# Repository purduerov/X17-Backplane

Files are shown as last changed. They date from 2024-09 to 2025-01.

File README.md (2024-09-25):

# Readme for X17-Backplane
This board routes signals and power between all the boards

Whenever you make a new part, download the datasheet and save it here _**and**_ with the part in the parts library

Always pull other people's changes before beginning to work
`git pull`

Be sure to push your changes after  working on them. Run:
1. `git add .` to add any files in this directory or a subdirectory
or `git add -u` to add any modified files
2. (Optional) `git clean -nX` to see what ignored files can be removed
	`git clean -fX` removes ignored files (Eagle backups)
3. `git commit -m "helpful commit message"` with a description of the work that you did
4. `git push` to push your work to github

Other helpful commands
* `git status` says information about modified and staged files
* `git log` shows the recent commits of the repository
* `git log filename.extension` show the recent commits for just that file
* `git checkout first-couple-letter-of-commit-id` lets you go back to a previous version
* `git checkout master` brings you back to the latest commit
* `git tag` lists the tags
* `git tag -a orderX -m "the version of the board placed for the X'th order"` tag a specific commit
* `git push --tags` needed to push tags to remote
* `git show orderX` show the commit log for the given tag
* `git checkout orderX` go back and interact with the files at the tagged commit

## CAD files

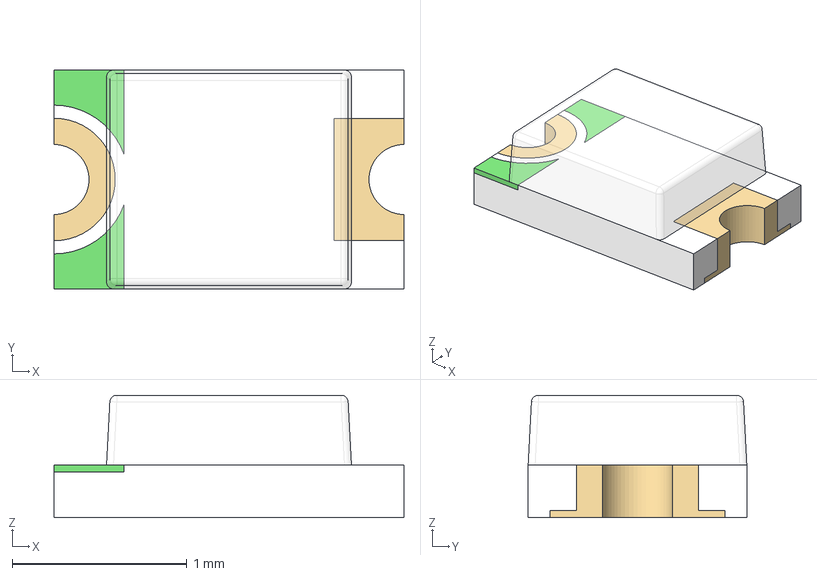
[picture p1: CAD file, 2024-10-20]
BackplaneSymbol+Footprint/150080SS75000/WL-SMCW_0805.step
2.00 x 1.25 x 0.7 mm
housing
marking x 2
cover
base_2
base

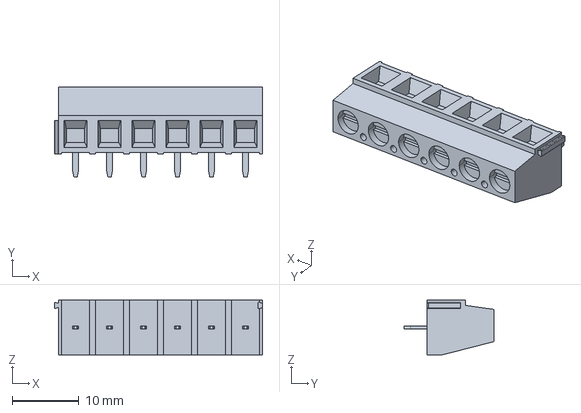
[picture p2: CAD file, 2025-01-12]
BackplaneSymbol+Footprint/282837_6/c-282837-6-g2-3d.stp
31.1 x 13.5 x 8.20 mm

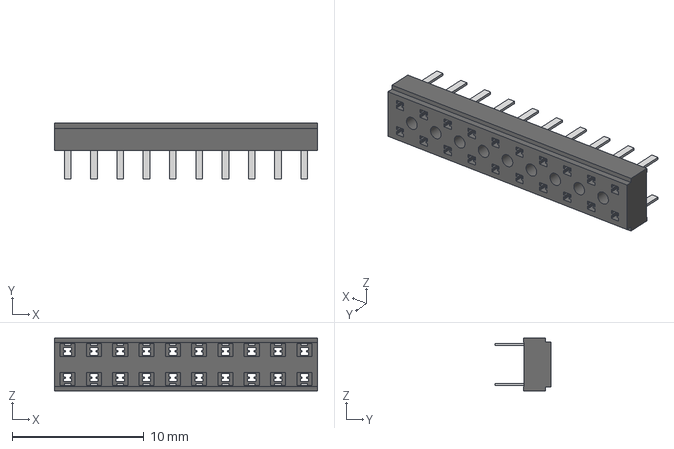
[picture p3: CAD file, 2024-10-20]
BackplaneSymbol+Footprint/CLT-110-01-F-D/CLT-110-01-F-D.step
20.0 x 4.28 x 4.00 mm
CLT-110-01-F-D_socket
C-1001-F-_pins

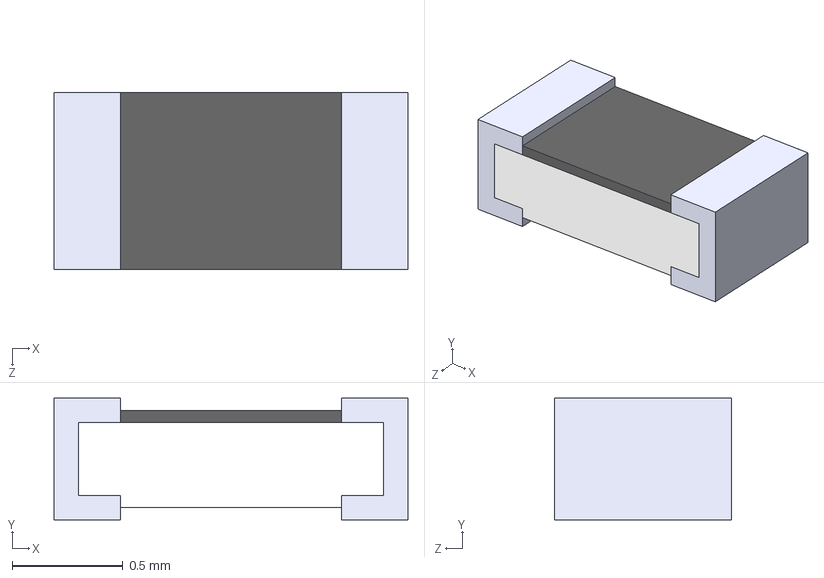
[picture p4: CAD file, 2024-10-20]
BackplaneSymbol+Footprint/CR0603_FX_6340ELF/CR0603-FX-6340ELF.step
1.60 x 0.55 x 0.8 mm

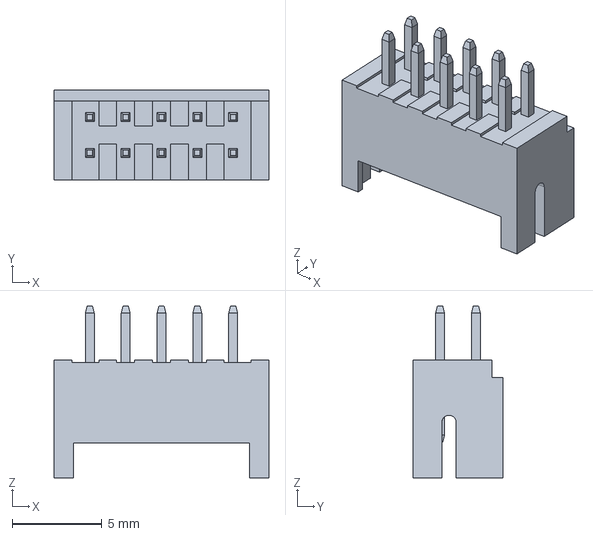
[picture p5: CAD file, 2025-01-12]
BackplaneSymbol+Footprint/DF11_10DP_2DSA_01_/DF11-10DP-2DSA(24).STEP
12.0 x 5.00 x 9.60 mm

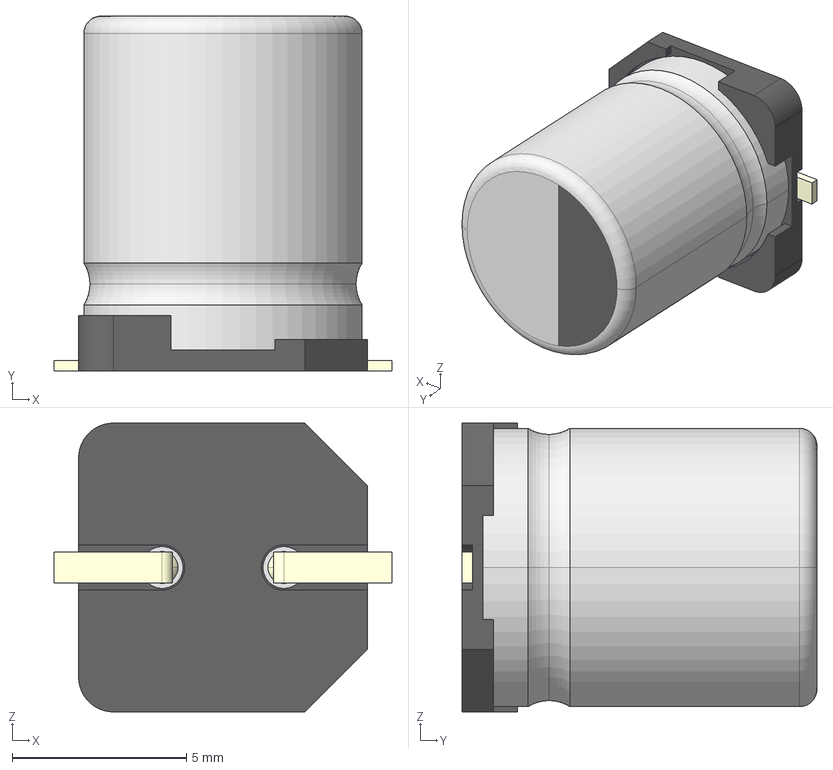
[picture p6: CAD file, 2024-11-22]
BackplaneSymbol+Footprint/EEE_FT1E561UP/8 SIZE CODE F.stp
9.70 x 10.2 x 8.30 mm

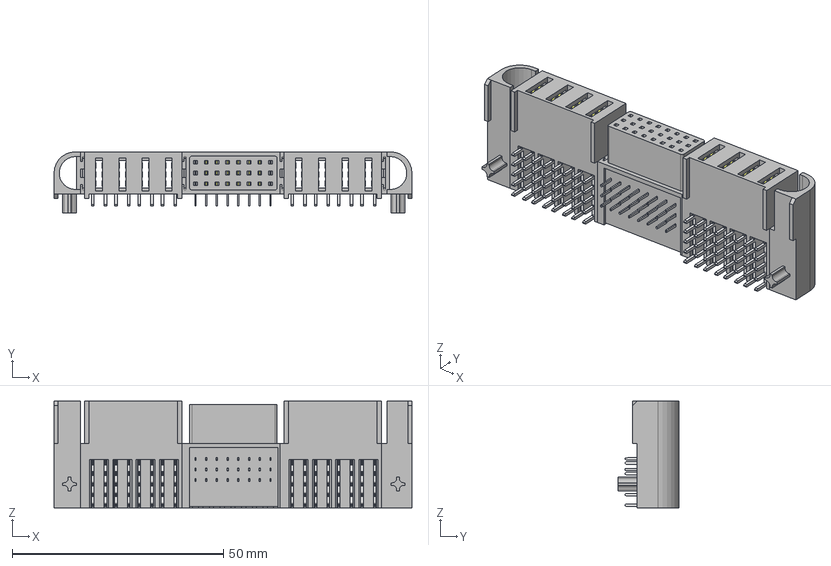
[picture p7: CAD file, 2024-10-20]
BackplaneSymbol+Footprint/ET60S-D04-3-08-D04-S-R1-S/ET60S-D04-3-08-D04-X-R1-S.step
84.8 x 14.5 x 25.2 mm
ET60S-24-R1_signal_terminal
ET60S-D04-R1_power_terminal x 2
ET60S-R1_guide_post_left
ET60S-D04-R1_power_pins x 2
ET60S-D04-R12_power_pins x 2
ET60S-R1_guide_post_right
ET60S-24-R1_signal_pins
ET60S-24-R12_signal_pins

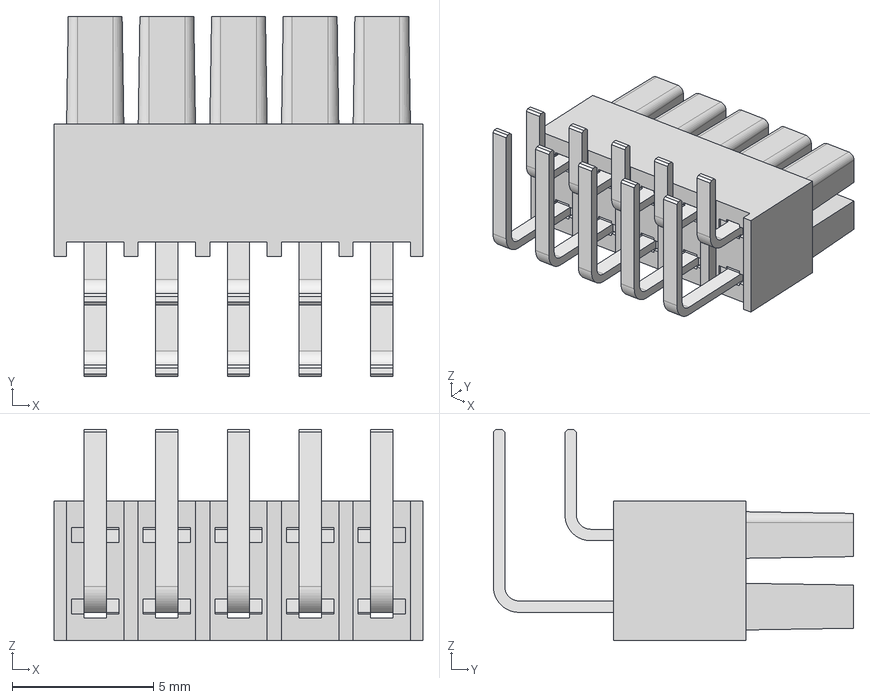
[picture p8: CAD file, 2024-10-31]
BackplaneSymbol+Footprint/IPS1-105-01-L-D-RA.step
13.1 x 12.8 x 7.49 mm
IPS1-105-01-L-D-RAt
IPS1-105-01-L-D-RA_pin

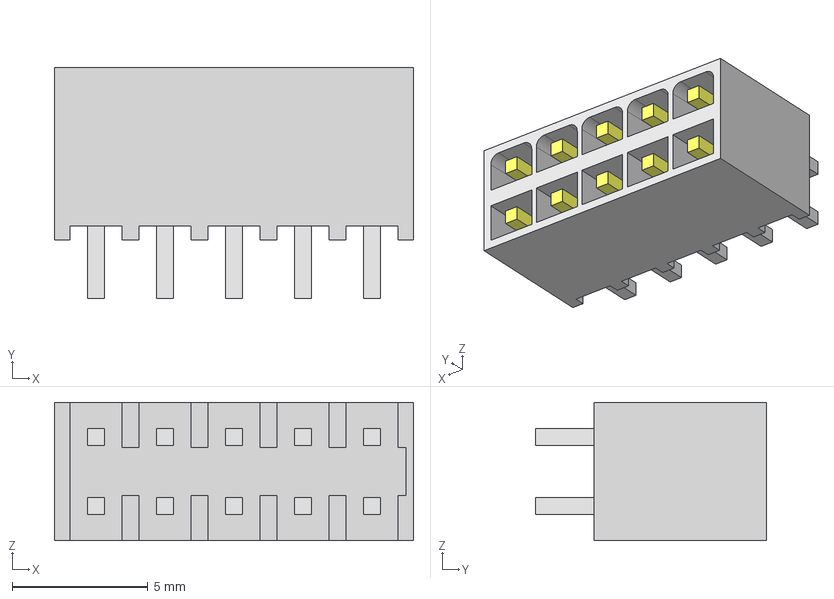
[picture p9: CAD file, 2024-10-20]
BackplaneSymbol+Footprint/IPT1-105-01-L-D/IPT1-105-01-L-D.step
13.2 x 8.51 x 5.08 mm
IPT1-105-01-L-D_terminal
IPT1-105-01-LD_pin
IPT1-105-01-LD2PIN

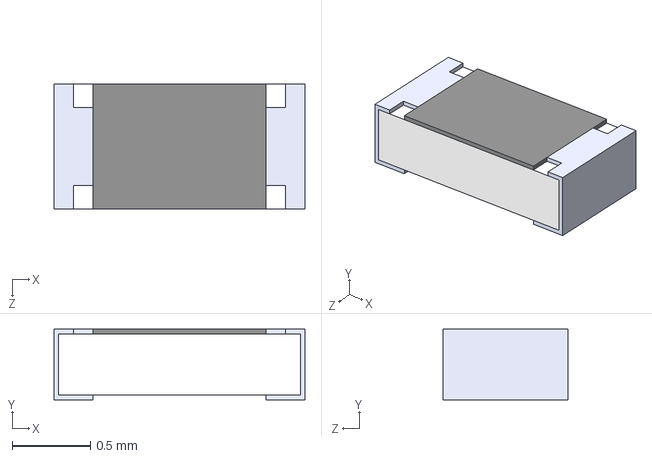
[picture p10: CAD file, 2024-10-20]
BackplaneSymbol+Footprint/RT0603BRE07250RL/RT0603BRE07250RL.step
1.60 x 0.45 x 0.8 mm

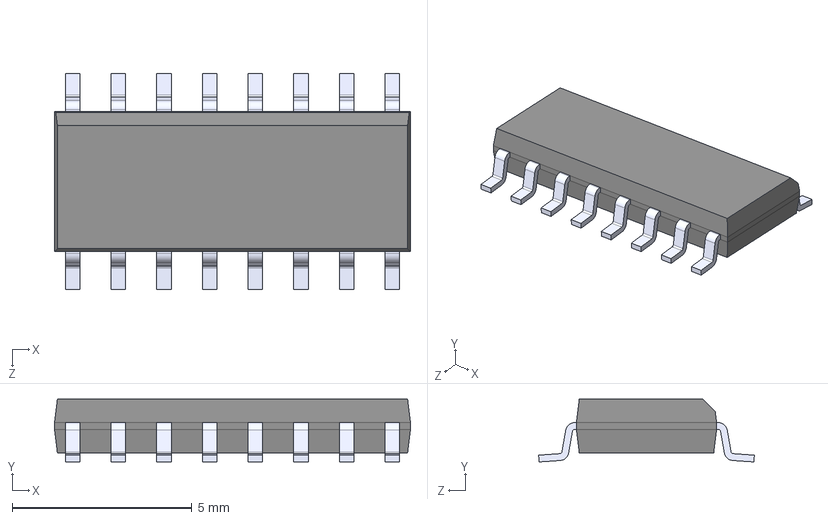
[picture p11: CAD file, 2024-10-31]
BackplaneSymbol+Footprint/Soldering Training Libraries/Soldering Training Libraries/CD74HC283M/CD74HC283M.step
9.90 x 1.75 x 6.00 mm

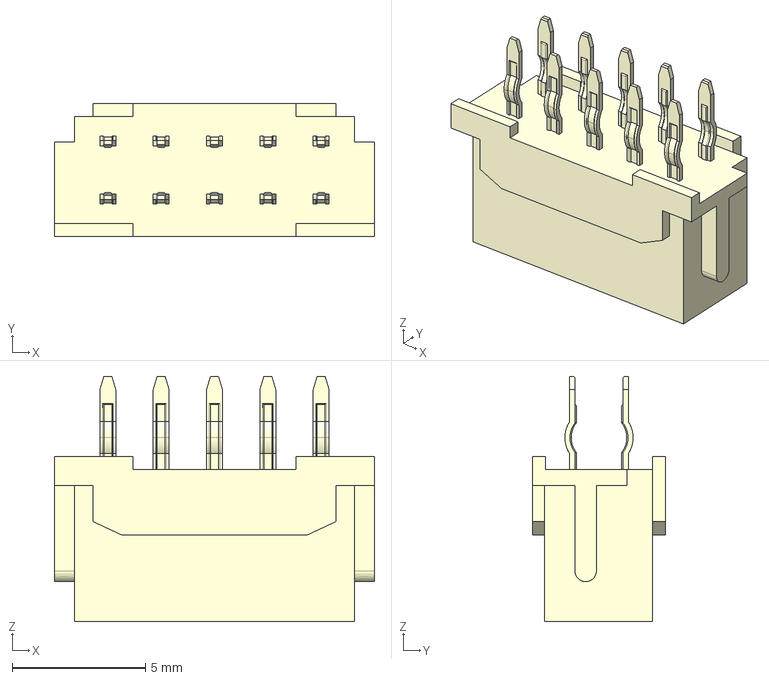
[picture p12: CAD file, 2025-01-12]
BackplaneSymbol+Footprint/DF11_10DP_2DSA_01_/DF11-10DS-2DSA(06).STEP
12.0 x 5.00 x 9.20 mm

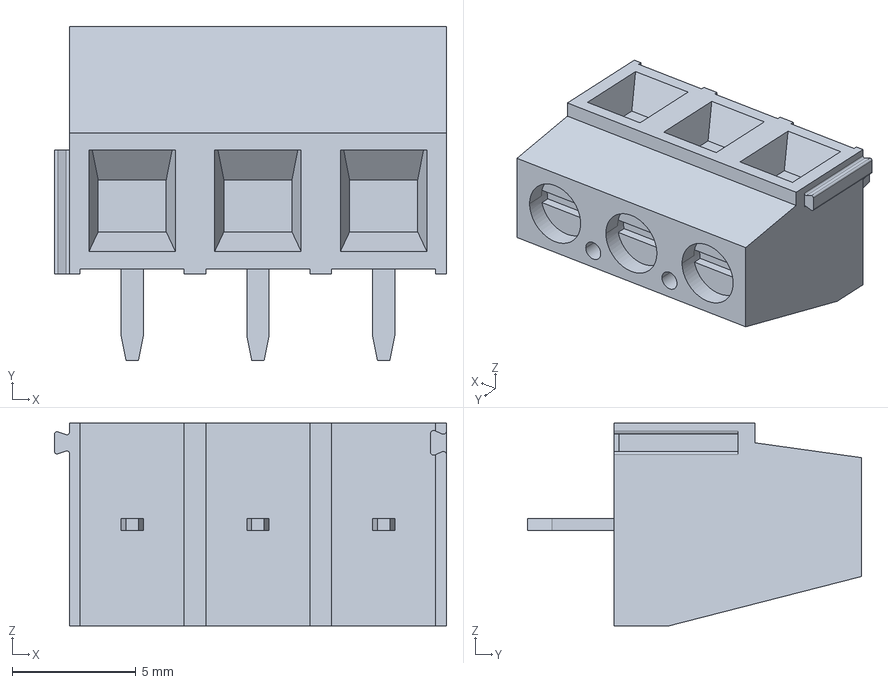
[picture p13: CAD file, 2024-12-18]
BackplaneSymbol+Footprint/282837_3/282837-3.step
15.8 x 13.5 x 8.20 mm

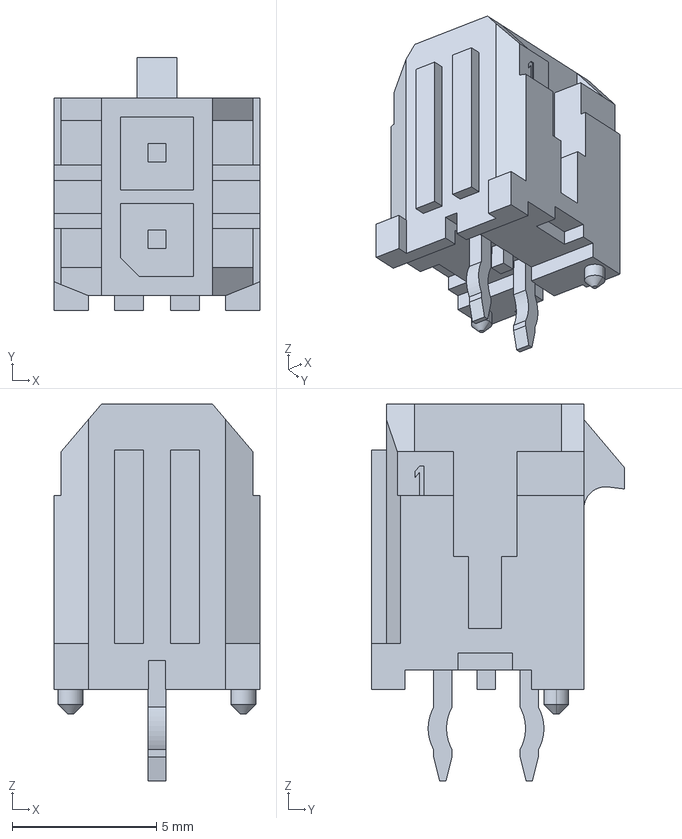
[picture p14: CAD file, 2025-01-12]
BackplaneSymbol+Footprint/430450212/430450212.stp
7.15 x 8.77 x 13.1 mm

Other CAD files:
BackplaneSymbol+Footprint/430450612/430450612.stp

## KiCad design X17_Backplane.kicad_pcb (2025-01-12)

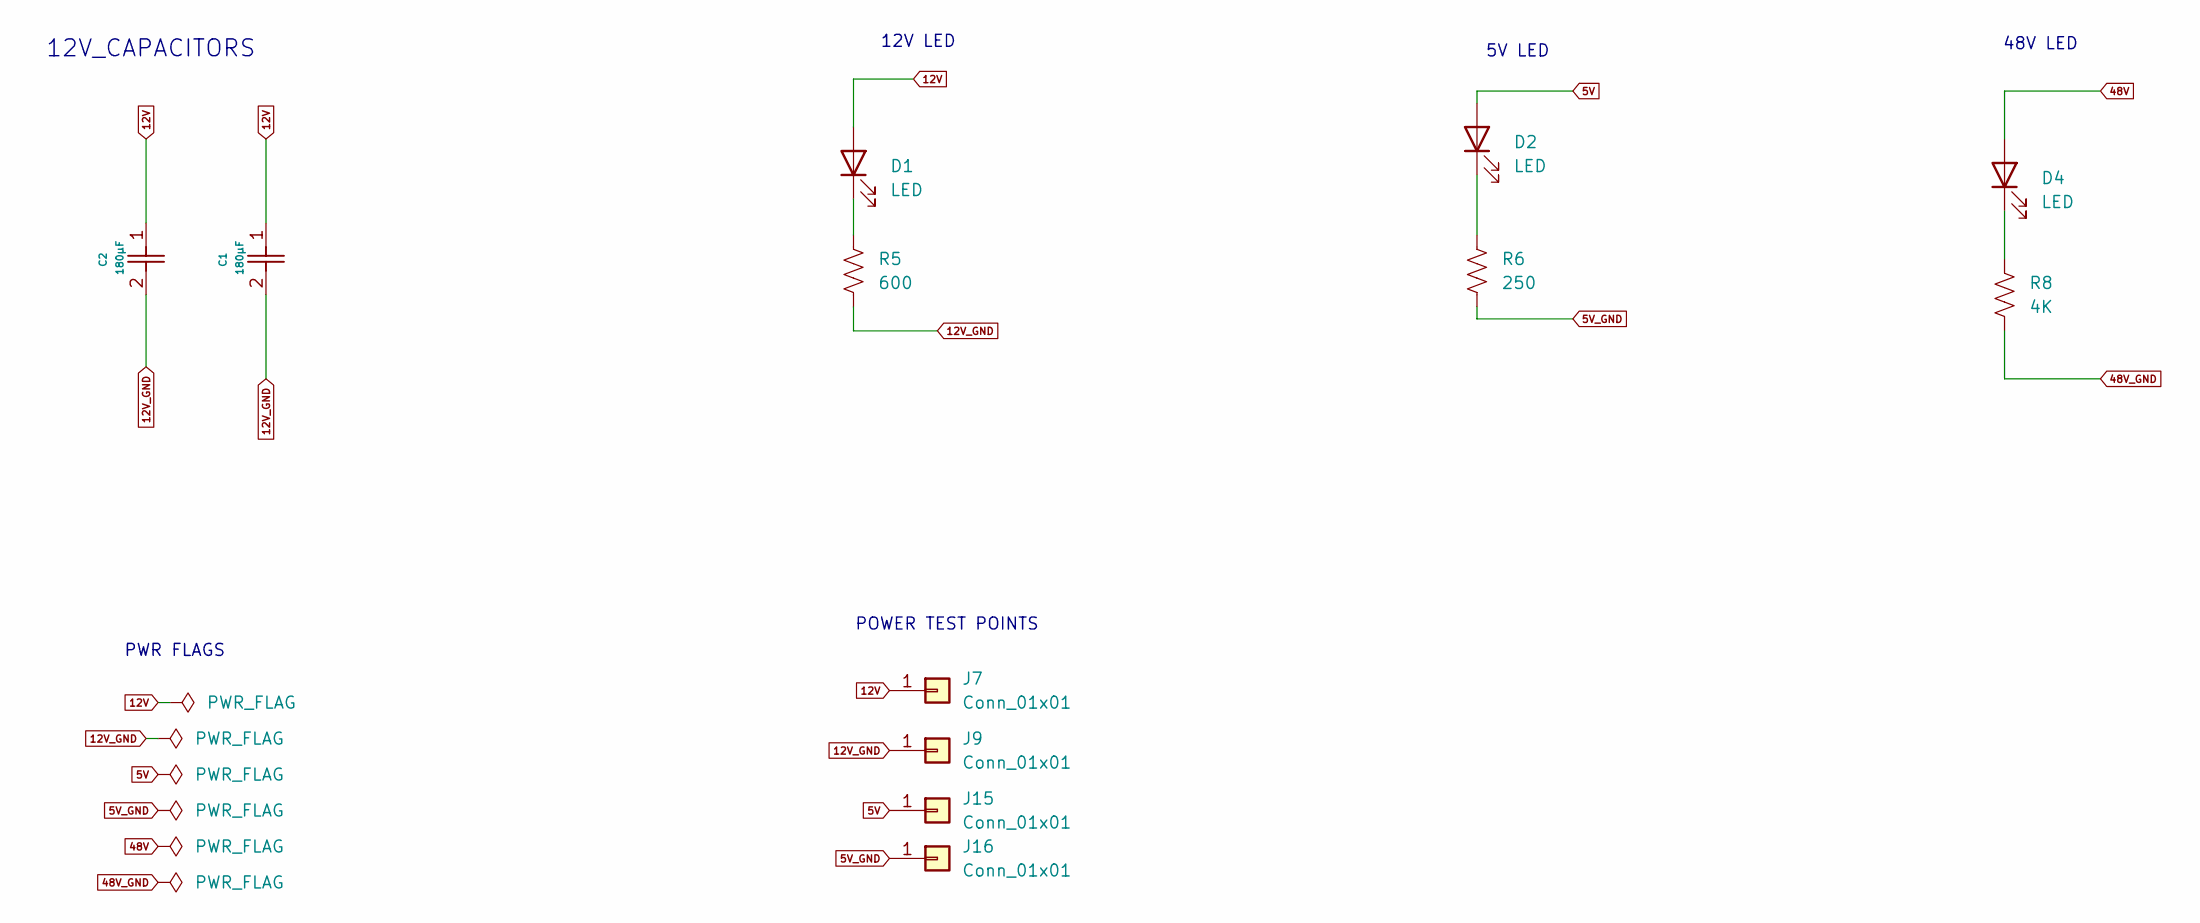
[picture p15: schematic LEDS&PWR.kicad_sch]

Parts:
C1, C2: 180μF; CAP_FT_F_PAN
D1, D2, D4: LED; LED_0805_2012Metric_Pad1.15x1.40mm_HandSolder
J7, J9, J15, J16: Conn_01x01; TestPoint_Pad_D4.0mm
R5: 600; R_0603_1608Metric_Pad0.98x0.95mm_HandSolder
R6: 250; R_0603_1608Metric_Pad0.98x0.95mm_HandSolder
R8: 4K; R_0603_1608Metric_Pad0.98x0.95mm_HandSolder

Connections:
5V: D2.2 (A), J15.1; also elsewhere on the board
5V_GND: J16.1, R6.2; also elsewhere on the board
12V: C1.1, C2.1, D1.2 (A), J7.1; also elsewhere on the board
12V_GND: C1.2, C2.2, J9.1, R5.2; also elsewhere on the board
48V: D4.2 (A); also elsewhere on the board
48V_GND: R8.2; also elsewhere on the board
unnamed: D1.1 (K), R5.1
unnamed: D2.1 (K), R6.1
unnamed: D4.1 (K), R8.1

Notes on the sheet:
12V_CAPACITORS
POWER TEST POINTS
12V LED
5V LED
48V LED
PWR FLAGS

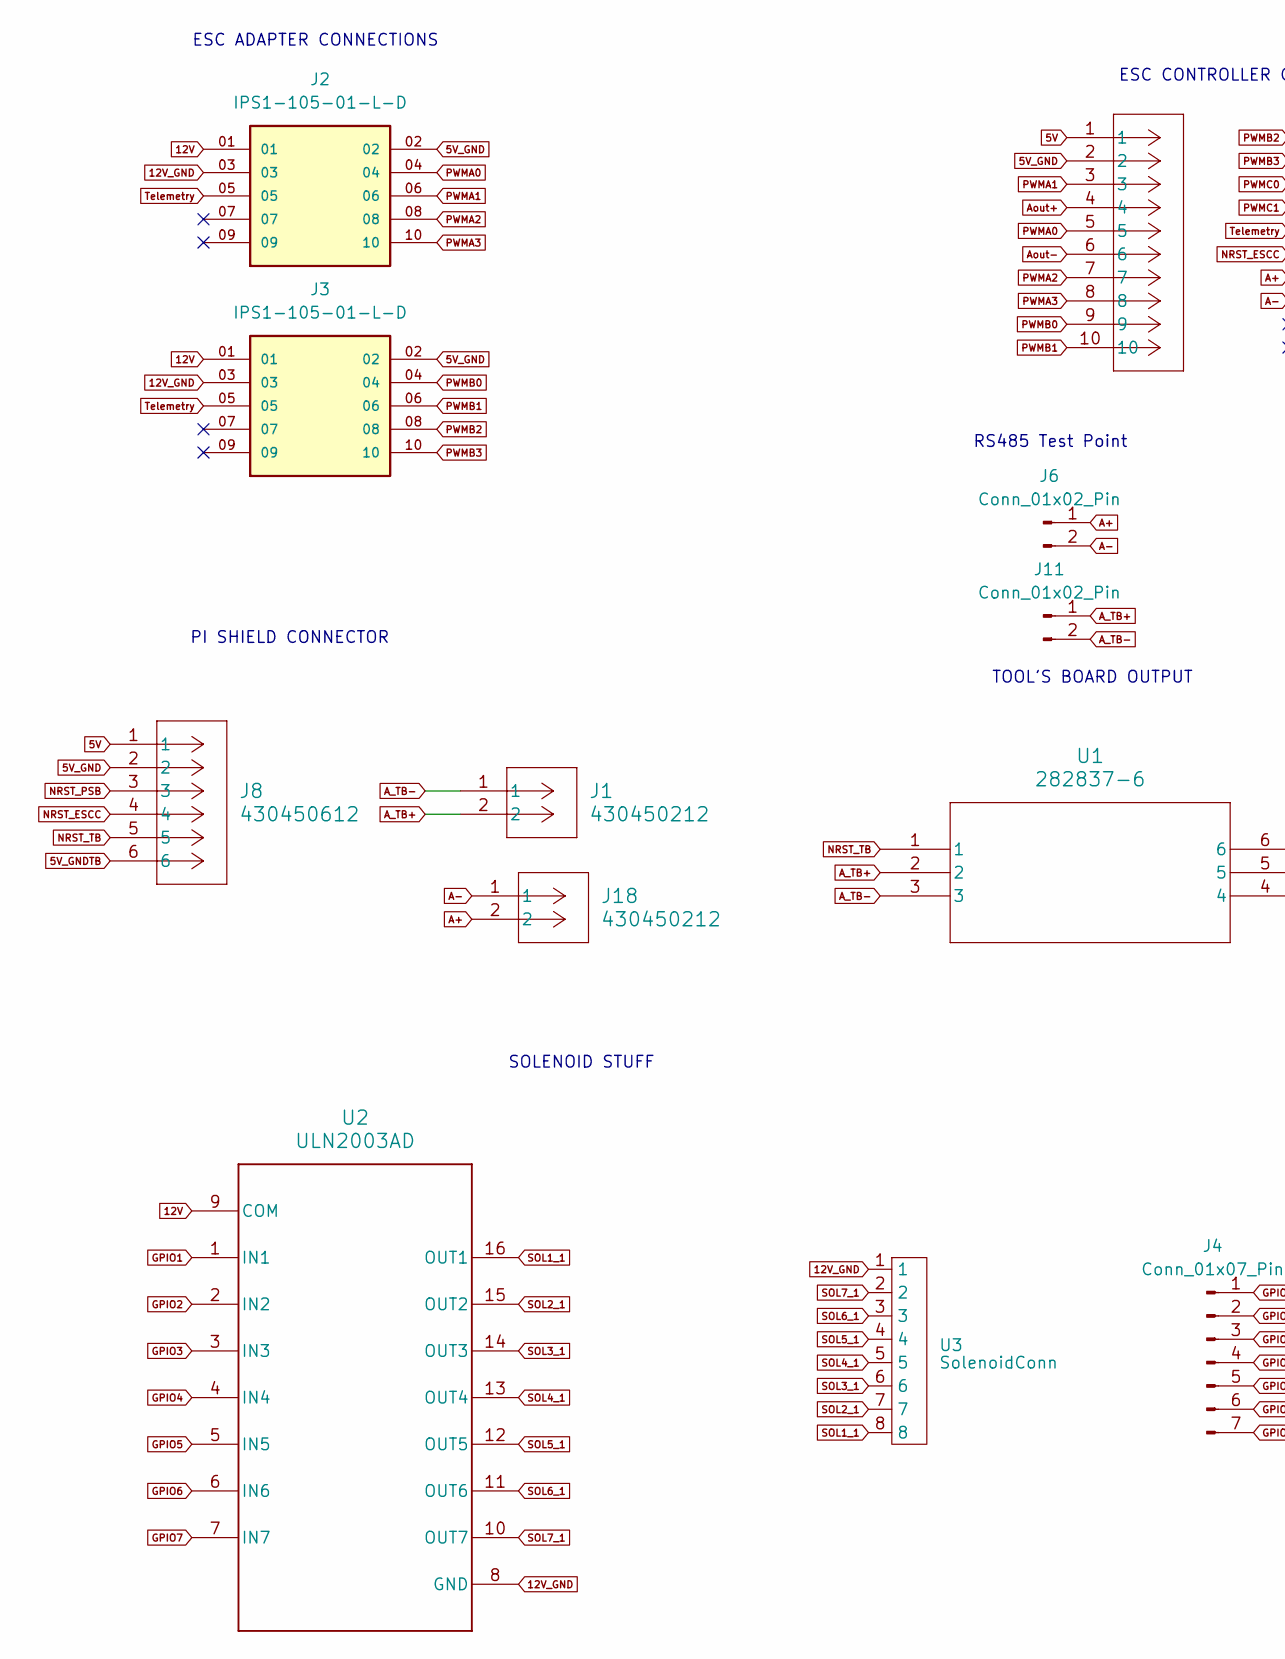
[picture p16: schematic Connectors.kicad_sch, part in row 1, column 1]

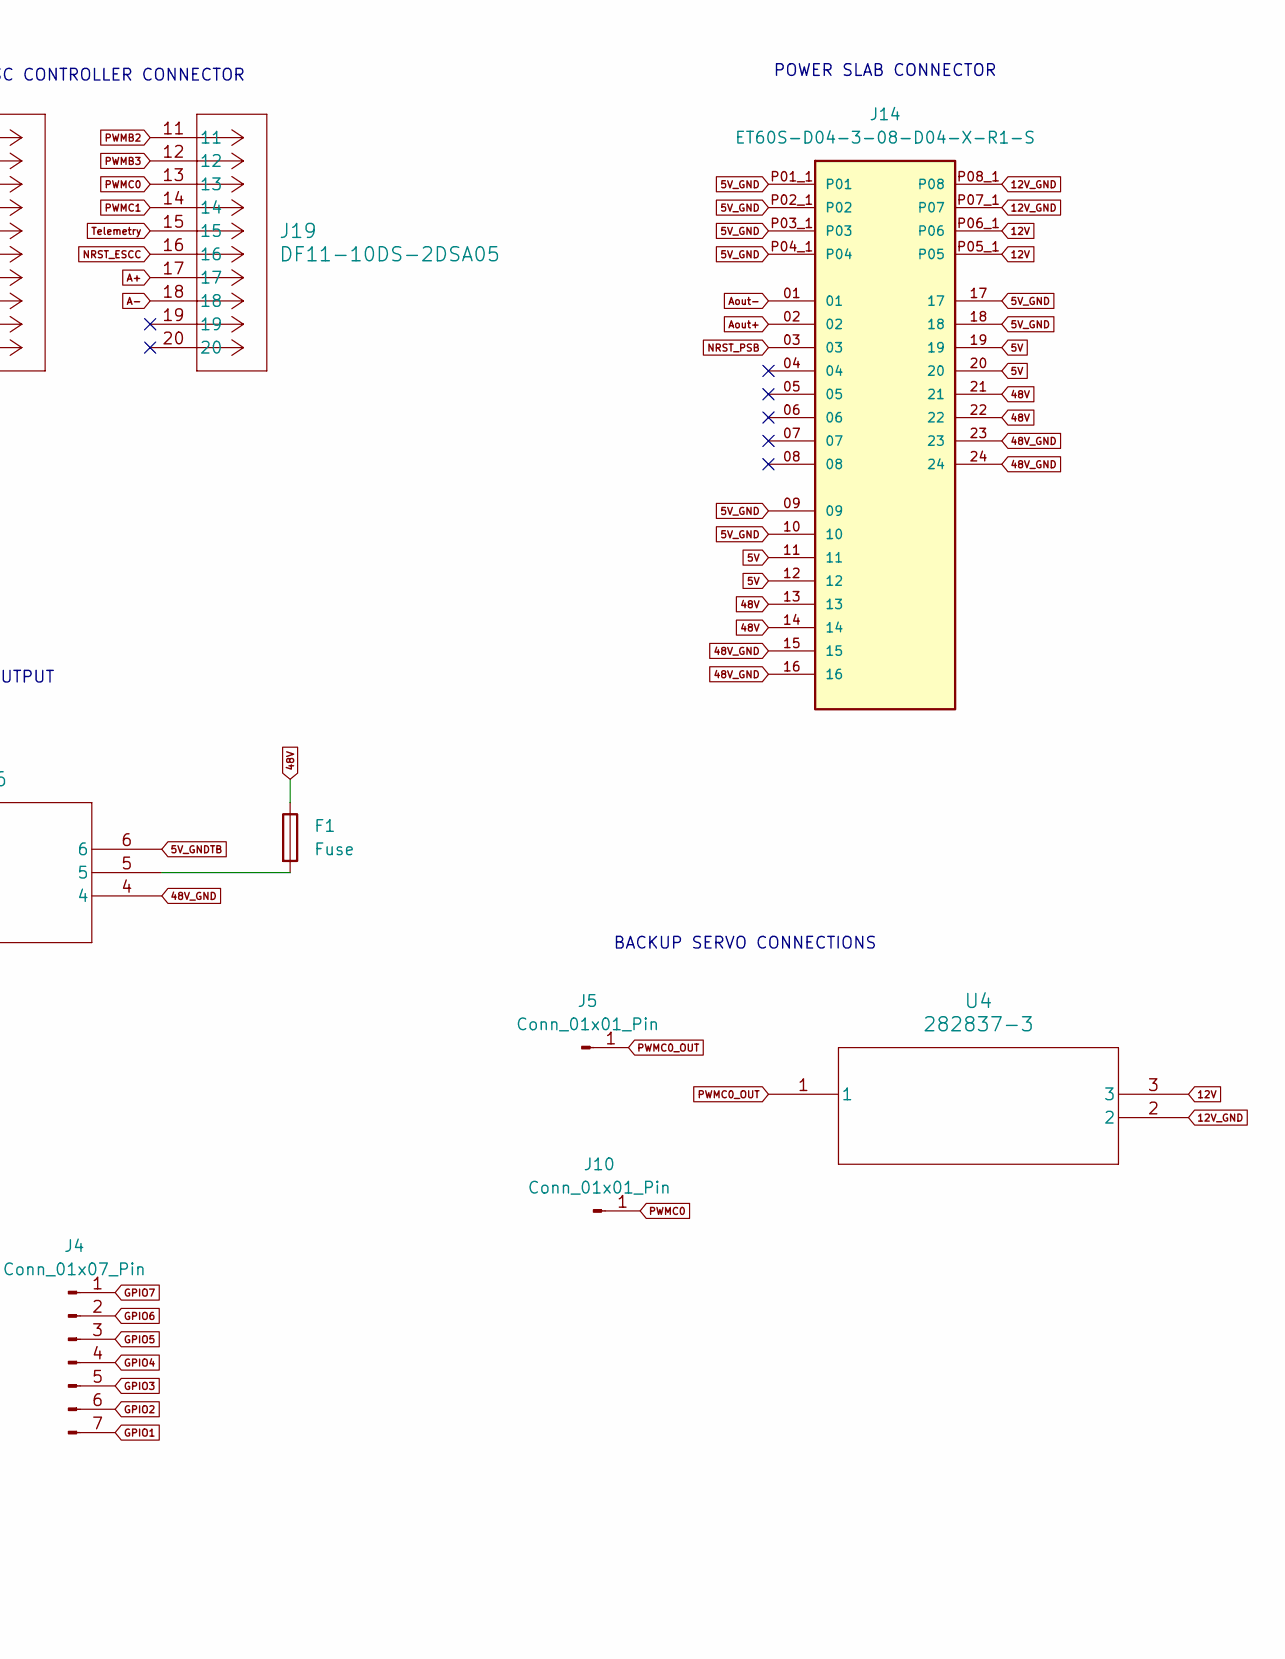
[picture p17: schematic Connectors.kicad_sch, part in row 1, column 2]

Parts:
F1: Fuse; Fuse_Littelfuse-NANO2-451_453
J1, J18: 430450212; CON_430450212_MOL
J2, J3: IPS1-105-01-L-D; PWM, 12V, GND JST Connector (real); PARTREV R
J4: Conn_01x07_Pin; PinHeader_1x07_P2.54mm_Vertical
J5, J10: Conn_01x01_Pin; PinHeader_1x01_P2.54mm_Vertical
J6, J11: Conn_01x02_Pin; PinHeader_1x02_P2.54mm_Vertical
J8: 430450612; CON_430450612_MOL
J14: ET60S-D04-3-08-D04-X-R1-S; SAMTEC_ET60S-D04-3-08-D04-X-R1-S; PARTREV G
J19: DF11-10DS-2DSA05; CON10_2X5_UF_DF11_HIR
U1: 282837-6; 282837-6_TYC
U2: ULN2003AD; D0016A_L
U3: SolenoidConn; PHOENIX_1778612
U4: 282837-3; 282837-3_TYC

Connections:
5V: J8.1, J14.11, J14.12, J14.19, J14.20, J19.1; also elsewhere on the board
5V_GND: J2.02, J3.02, J8.2, J14.09, J14.10, J14.17, J14.18, J14.P01_1 (P01), J14.P02_1 (P02), J14.P03_1 (P03), J14.P04_1 (P04), J19.2; also elsewhere on the board
5V_GNDTB: J8.6, U1.6
12V: J2.01, J3.01, J14.P05_1 (P05), J14.P06_1 (P06), U2.9 (COM), U4.3; also elsewhere on the board
12V_GND: J2.03, J3.03, J14.P07_1 (P07), J14.P08_1 (P08), U2.8 (GND), U3.1, U4.2; also elsewhere on the board
48V: F1.1, J14.13, J14.14, J14.21, J14.22; also elsewhere on the board
48V_GND: J14.15, J14.16, J14.23, J14.24, U1.4; also elsewhere on the board
A+: J6.1, J18.2, J19.17
A-: J6.2, J18.1, J19.18
A_TB+: J1.2, J11.1, U1.2
A_TB-: J1.1, J11.2, U1.3
Aout+: J14.02, J19.4
Aout-: J14.01, J19.6
GPIO1: J4.7, U2.1 (IN1)
GPIO2: J4.6, U2.2 (IN2)
GPIO3: J4.5, U2.3 (IN3)
GPIO4: J4.4, U2.4 (IN4)
GPIO5: J4.3, U2.5 (IN5)
GPIO6: J4.2, U2.6 (IN6)
GPIO7: J4.1, U2.7 (IN7)
NRST_ESCC: J8.4, J19.16
NRST_PSB: J8.3, J14.03
NRST_TB: J8.5, U1.1
unnamed: F1.2, U1.5
PWMA0: J2.04, J19.5
PWMA1: J2.06, J19.3
PWMA2: J2.08, J19.7
PWMA3: J2.10, J19.8
PWMB0: J3.04, J19.9
PWMB1: J3.06, J19.10
PWMB2: J3.08, J19.11
PWMB3: J3.10, J19.12
PWMC0: J10.1, J19.13
PWMC0_OUT: J5.1, U4.1
PWMC1: J19.14
SOL1_1: U2.16 (OUT1), U3.8
SOL2_1: U2.15 (OUT2), U3.7
SOL3_1: U2.14 (OUT3), U3.6
SOL4_1: U2.13 (OUT4), U3.5
SOL5_1: U2.12 (OUT5), U3.4
SOL6_1: U2.11 (OUT6), U3.3
SOL7_1: U2.10 (OUT7), U3.2
Telemetry: J2.05, J3.05, J19.15

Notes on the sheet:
PI SHIELD CONNECTOR
TOOL'S BOARD OUTPUT
ESC CONTROLLER CONNECTOR
BACKUP SERVO CONNECTIONS
POWER SLAB CONNECTOR
ESC ADAPTER CONNECTIONS
RS485 Test Point
SOLENOID STUFF

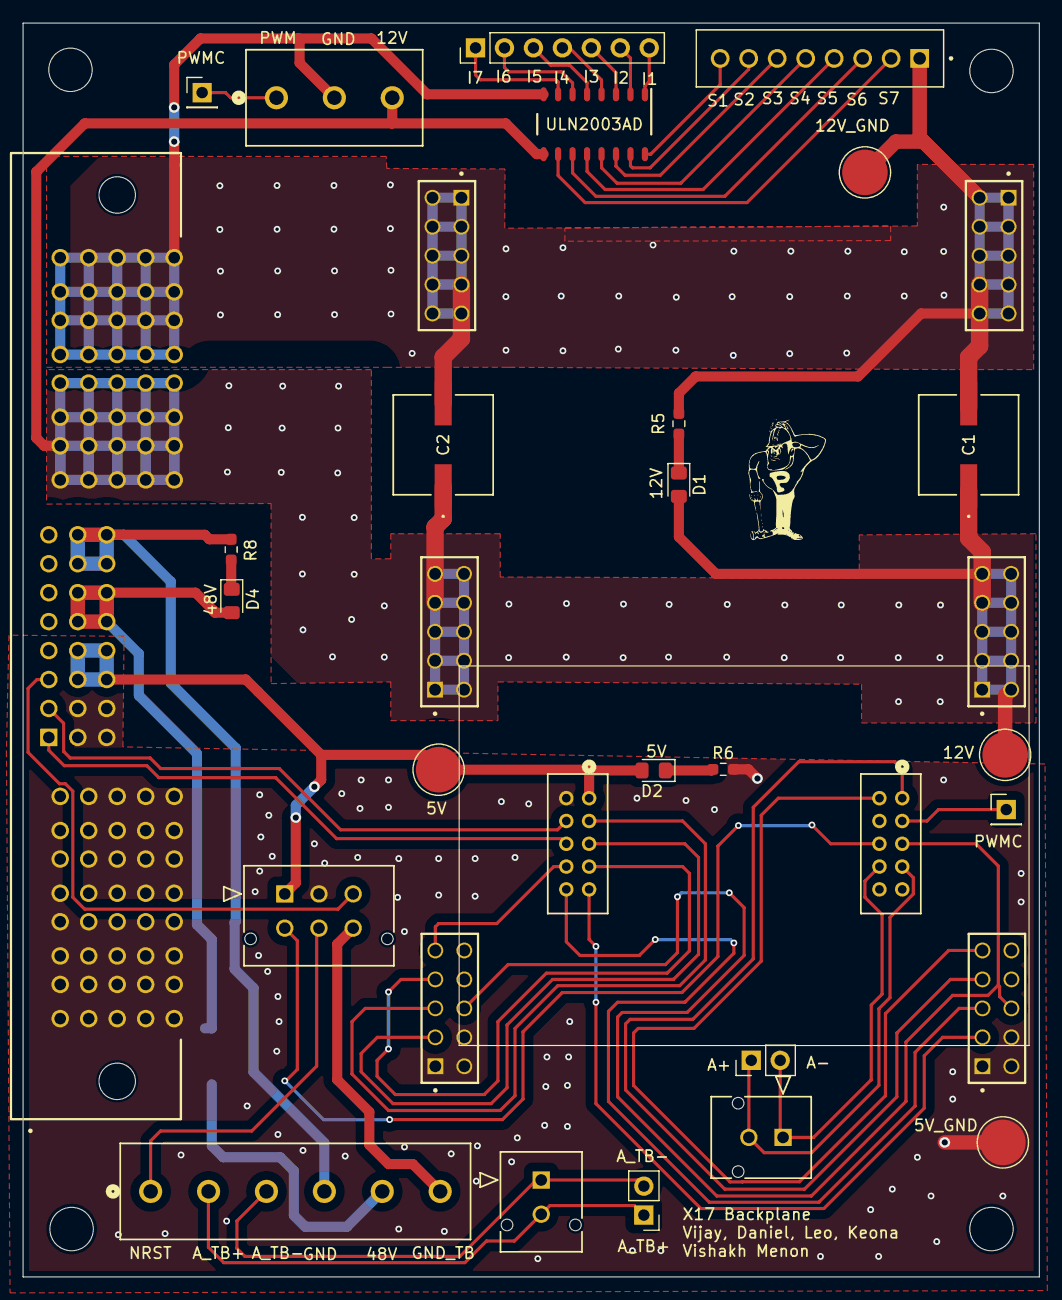
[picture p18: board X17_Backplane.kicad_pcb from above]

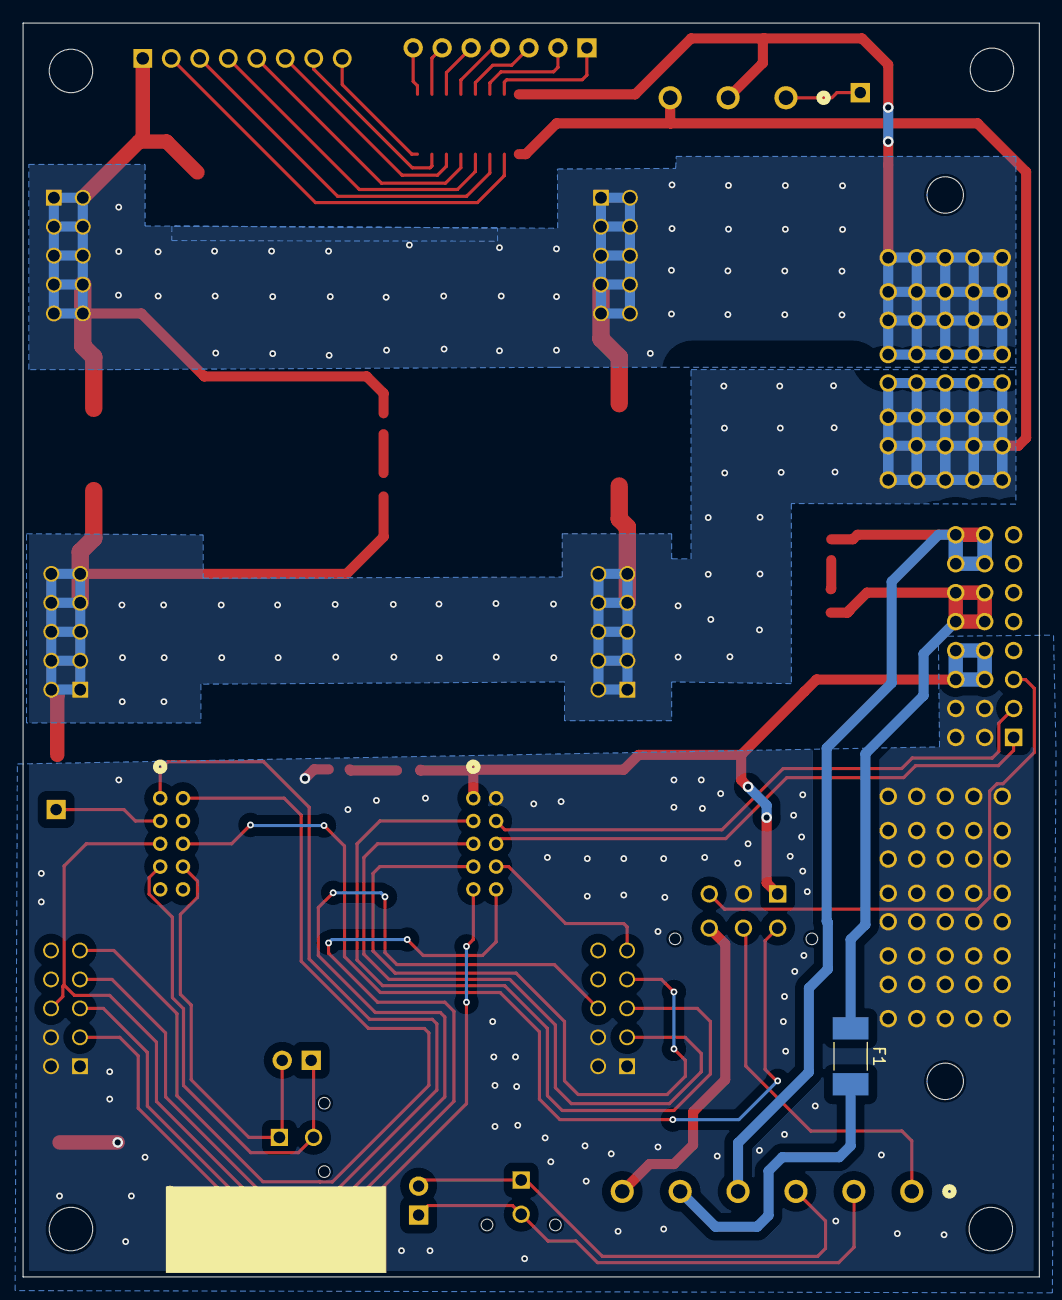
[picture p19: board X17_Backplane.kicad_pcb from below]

Board: 2 copper layers, 89.2 x 110.0 mm, 33 parts (5 on the bottom side), 45 nets.

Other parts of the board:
H1, H1#2, H1#3, H1#4: 6-32-HOLE

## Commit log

2024-10-09 All work thus far.
    [X17_Backplane.kicad_pcb, X17_Backplane.kicad_sch]
2024-10-10 Work done on 10/9/24
    [X17_Backplane.kicad_sch]
2024-10-12 Work on 10/12/24
    [X17_Backplane.kicad_sch]
2024-10-12 Final Work 10/12/2024
    [Connectors.kicad_sch, X17_Backplane.kicad_pcb, X17_Backplane.kicad_sch]
2024-10-17 Work done on 10/16/2024
    [Connectors.kicad_sch, LEDS&PWR.kicad_sch, X17_Backplane.kicad_pcb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]
2024-10-19 Work done on 10/19/2024
    [Connectors.kicad_sch, LEDS&PWR.kicad_sch]
2024-10-20 Connector footprint
    [Connectors.kicad_sch, LEDS&PWR.kicad_sch]
2024-10-20 added board dimensions
    [X17_Backplane.kicad_pcb]
2024-10-20 Work done after office hours on 10/20/24
    [CLT-110-01-F-D.step, CLT-110-01-F-D.stp, CR0603-FX-6340ELF.step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]
2024-10-24 Work done on 10/23/2024
    [Connectors.kicad_sch, LEDS&PWR.kicad_sch]
2024-10-25 Updates on 10/24/2024
    [Connectors.kicad_sch, LEDS&PWR.kicad_sch]
2024-10-25 Update 10/25/2024 (again lol)
    [Connectors.kicad_sch]
2024-10-31 Work done on 10/30/2024
    [CD74HC283M.step, Connectors.kicad_sch, IPS1-105-01-L-D-RA.step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]
2024-10-31 Work on 10/31/2024
    [Connectors.kicad_sch, X17_Backplane.kicad_pcb]
2024-11-02 Work on 11/2/2024
    [Connectors.kicad_sch, X17_Backplane.kicad_pcb]
2024-11-07 Work done on 11/06/2024
    [Connectors.kicad_sch, LEDS&PWR.kicad_sch, X17_Backplane.kicad_pcb]
2024-11-09 Work done on 11/09/2024
    [Connectors.kicad_sch, X17_Backplane.kicad_pcb]
2024-11-12 Work done on 11/12/2024
    [Connectors.kicad_sch, X17_Backplane.kicad_pcb]
2024-11-13 Work done 11/13/2024
    [X17_Backplane.kicad_pcb]
2024-11-15 Work done on 11/14/2024
    [Connectors.kicad_sch, X17_Backplane.kicad_pcb]
2024-11-17 Work done on11/17/2024
    I'm cooked yo
    [Connectors.kicad_sch, X17_Backplane.kicad_pcb]
2024-11-21 WORK done on 11/20/2024
    I'm losing my shiiiiiii
    #SlayedTheDayAway
    [Connectors.kicad_sch, X17_Backplane.kicad_pcb]
2024-11-21 11/20/2024
    Yo fr tho Daniel and Vijay save my ass from these PCB demons
    [X17_Backplane.kicad_pcb]
2024-11-21 Work done on 11/21/2024
    Made traces more size efficient(I think)
    [X17_Backplane.kicad_pcb]
2024-11-22 Work done on 11/22/2024
    [8 SIZE CODE F.stp, Connectors.kicad_sch, LEDS&PWR.kicad_sch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]
2024-11-23 Work done on 11/23/2024
    [LEDS&PWR.kicad_sch, X17_Backplane.kicad_pcb]
2024-12-14 Work done on 12/13/2024
    [Connectors.kicad_sch, LEDS&PWR.kicad_sch, X17_Backplane.kicad_pcb]
2024-12-15 Work done on 12/14/2024
    [Connectors.kicad_sch, X17_Backplane.kicad_pcb]
2024-12-15 More work done on 12/14/2024
    [X17_Backplane.kicad_pcb]
2024-12-16 Work done on 12/16/2024
    [Connectors.kicad_sch, X17_Backplane.kicad_pcb]
2024-12-16 Work done on 12/16/2024 v2
    [Connectors.kicad_sch, X17_Backplane.kicad_pcb]
2024-12-17 Work done on 12/17/2024
    [Connectors.kicad_sch, LEDS&PWR.kicad_sch, X17_Backplane.kicad_pcb]
2024-12-18 Work on 12/17/2024 v2
    [X17_Backplane.kicad_pcb]
2024-12-18 work on 12/17/2024 v3
    [X17_Backplane.kicad_pcb]
2024-12-18 Work done on 12/17/2024 final
    Am i done??????
    [282837-3.step, Connectors.kicad_sch, X17_Backplane.kicad_pcb]
2024-12-18 Work done on 12/18/2024
    [X17_Backplane.kicad_pcb]
2024-12-30 board review 12/30 midway
    [Connectors.kicad_sch, LEDS&PWR.kicad_sch, X17_Backplane.kicad_pcb]
2025-01-03 changes 1/3/25
    [Connectors.kicad_sch, X17_Backplane.kicad_pcb]
2025-01-08 correct solenoid connector + some silkscreen additions
    [Connectors.kicad_sch, LEDS&PWR.kicad_sch, X17_Backplane.kicad_pcb]
2025-01-09 some pinout changes
    [Connectors.kicad_sch, X17_Backplane.kicad_pcb]
2025-01-10 all ordered!
    [Connectors.kicad_sch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]
2025-01-12 update 3d model
    [430450212.stp, 430450612.stp, DF11-10DP-2DSA(24).STEP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]
2025-01-12 2oz has larger min spacing
    [X17_Backplane-B_Cu.gbl, X17_Backplane-B_Mask.gbs, X17_Backplane-B_Paste.gbp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]

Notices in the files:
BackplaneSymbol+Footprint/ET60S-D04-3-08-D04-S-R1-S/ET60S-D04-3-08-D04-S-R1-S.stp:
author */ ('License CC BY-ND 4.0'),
